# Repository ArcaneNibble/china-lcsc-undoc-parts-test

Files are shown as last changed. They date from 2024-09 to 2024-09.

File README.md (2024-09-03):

# China / LCSC poorly-documented parts tester PCB

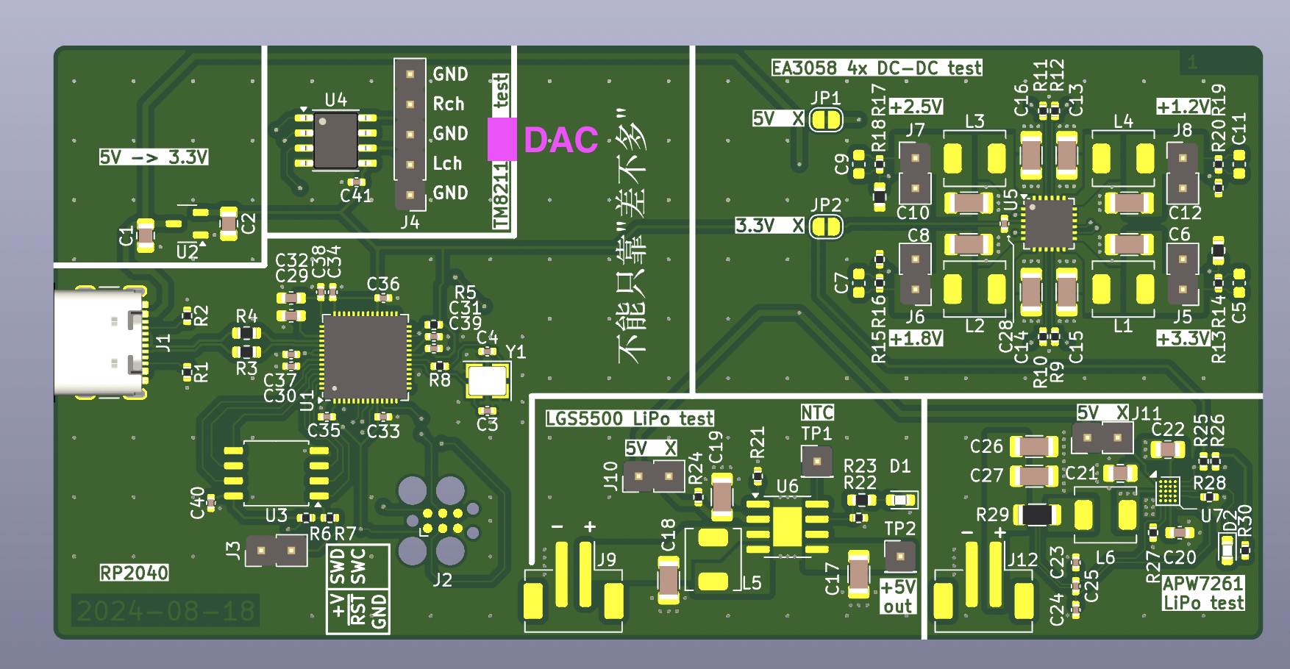
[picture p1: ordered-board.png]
3d render of board


## TM8211

This is a cheap I2S DAC that looks like it is intended for set-top-boxes. Allegedly, there is no minium clock speed. The goal is to determine if this is indeed true, in which case it can be bit-banged instead of doing proper I2S with a continuously-running clock. If it were to be the case, we would want to know the output impedance of the DAC.

### Status

I haven't managed to get this chip to output anything at all so far, even with a continuous clock. Further investigation needed.

## EA3058

This is a 4-channel buck converter. I wanted to characterize its performance in more detail than the few graphs in the datasheet.

### Status

The zero-load performance seems quite poor on the 1.2 V output. Further measurements have not been made yet.

## LGS5500

This is a LiPo charger and boost converter with automagic power path / load sharing. It appears to be perfectly-suited for battery-powered "maker" projects, especially ones that need 5 V and/or want to be able to push batteries to ~3 V rather than ~3.4 V (with an ultra-low-dropout regulator) or even higher voltages (using less and less of the battery capacity). Once again I wanted to characterize the performance in more detail than in the datasheet.

### Status

There is somewhat undesired behavior if there is no battery connected. Automagic power path / load sharing appears to work very well, but more measurements need to be made of whether spikes/dips happen. Needs more testing of the boost converter under load.

## APW7261

This is another LiPo charger and boost converter that is especially cheap. It was a bit unclear how (in)convenient it would be to use. It was also a test of using WLCSPs and pushing JLCPCB minimums.

### Status

This is clearly designed for legacy OTG, and it doesn't have the same type of automagic power path / load sharing as the previous part. It was assembled successfully without any issues.

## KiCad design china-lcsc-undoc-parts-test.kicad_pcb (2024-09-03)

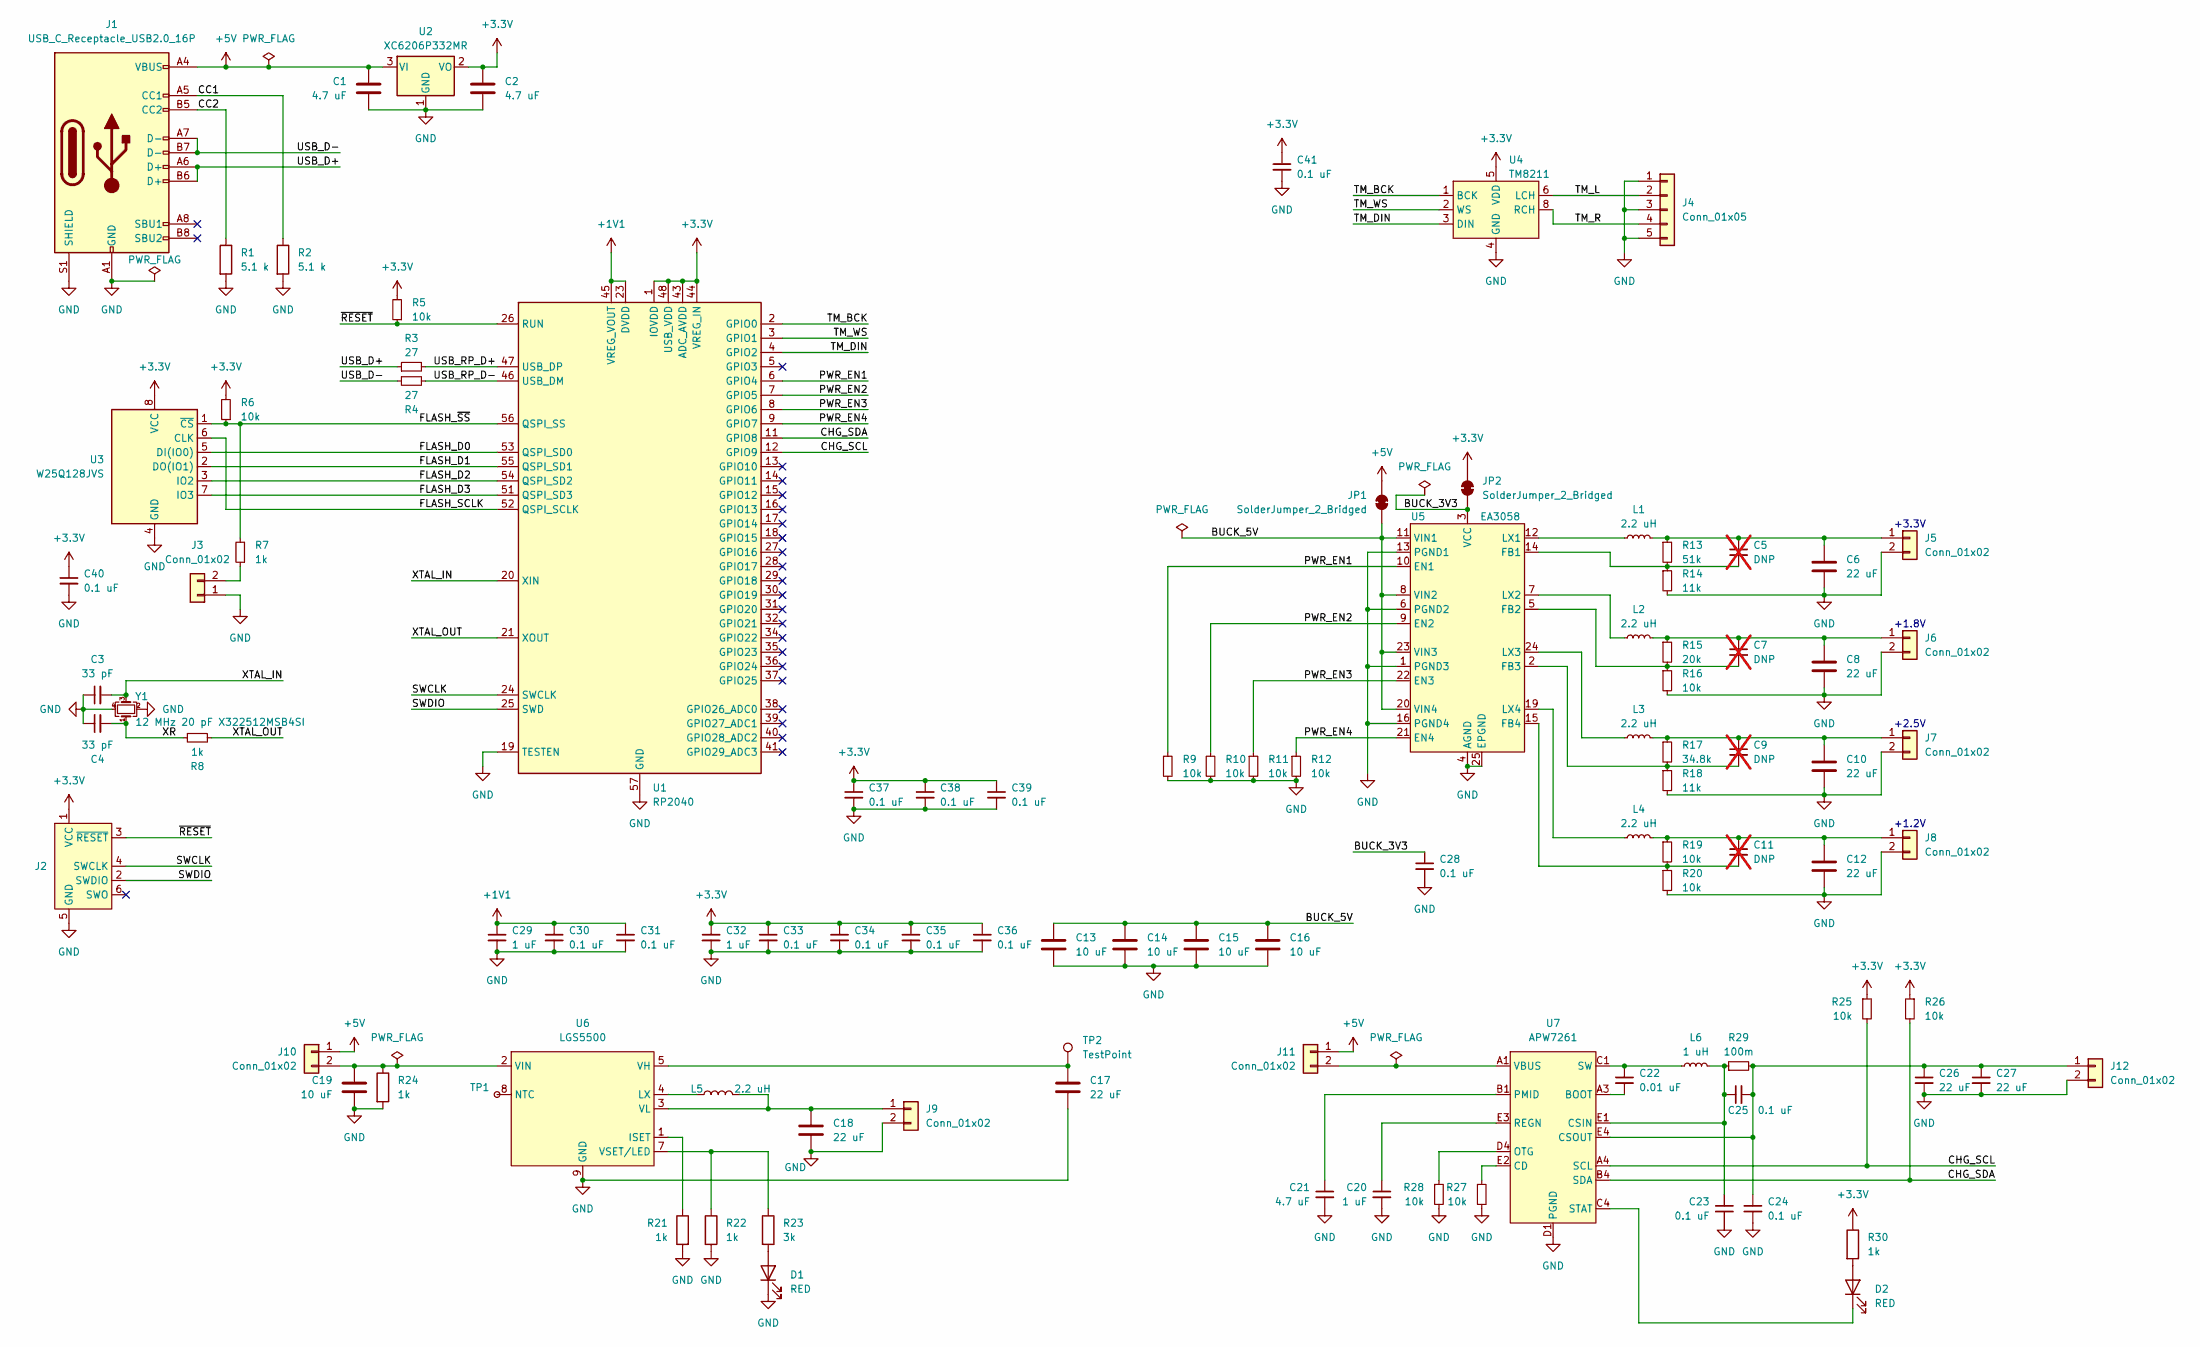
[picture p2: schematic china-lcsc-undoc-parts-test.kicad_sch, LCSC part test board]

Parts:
C1, C2, C21: 4.7 uF; C_0805_2012Metric; LCSC C1779
C3, C4: 33 pF; C_0402_1005Metric; LCSC C1562
C5, C7, C9, C11: DNP; C_0603_1608Metric; not fitted
C6, C8, C10, C12, C17, C18, C26, C27: 22 uF; C_1206_3216Metric; LCSC C12891
C13, C14, C15, C16, C19: 10 uF; C_1206_3216Metric; LCSC C13585
C20, C29, C32: 1 uF; C_0603_1608Metric; LCSC C15849
C22: 0.01 uF; C_0805_2012Metric; LCSC C1710
C23, C24, C25, C28, C30, C31, C33, C34, C35, C36, C37, C38, C39, C40, C41: 0.1 uF; C_0402_1005Metric; LCSC C1525
D1, D2: RED; LED_0603_1608Metric; LCSC C2286
J1: USB_C_Receptacle_USB2.0_16P; USB_C_Receptacle_GCT_USB4105-xx-A_16P_TopMnt_Horizontal; LCSC C2765186
J2: Conn_ARM_SWD_TagConnect_TC2030; Tag-Connect_TC2030-IDC-FP_2x03_P1.27mm_Vertical
J3, J5, J6, J7, J8, J10, J11: Conn_01x02; PinHeader_1x02_P2.54mm_Vertical
J4: Conn_01x05; PinHeader_1x05_P2.54mm_Vertical
J9, J12: Conn_01x02; JST_PH_B2B-PH-SM4-TB_1x02-1MP_P2.00mm_Vertical; LCSC C160352
JP1, JP2: SolderJumper_2_Bridged; SolderJumper-2_P1.3mm_Bridged_RoundedPad1.0x1.5mm
L1, L2, L3, L4, L5: 2.2 uH; L_Changjiang_FXL0420; LCSC C167206
L6: 1 uH; L_Changjiang_FXL0420; LCSC C167203
R1, R2: 5.1 k; R_0402_1005Metric; LCSC C25905
R3, R4: 27; R_0603_1608Metric; LCSC C25190
R5, R6, R9, R10, R11, R12, R16, R19, R20, R25, R26, R27, R28: 10k; R_0402_1005Metric; LCSC C25744
R7, R8, R21, R22, R24, R30: 1k; R_0402_1005Metric; LCSC C11702
R13: 51k; R_0402_1005Metric; LCSC C25794
R14, R18: 11k; R_0603_1608Metric; LCSC C25950
R15: 20k; R_0402_1005Metric; LCSC C25765
R17: 34.8k; R_0402_1005Metric; LCSC C47493
R23: 3k; R_0603_1608Metric; LCSC C4211
R29: 100m; R_1206_3216Metric; LCSC C188071
TP1: TestPoint_Small; PinHeader_1x01_P2.54mm_Vertical
TP2: TestPoint; PinHeader_1x01_P2.54mm_Vertical
U1: RP2040; QFN-56-1EP_7x7mm_P0.4mm_EP3.2x3.2mm; LCSC C2040
U2: XC6206P332MR; SOT-23-3; LCSC C5446
U3: W25Q128JVS; SOIC-8_5.23x5.23mm_P1.27mm; LCSC C97521
U4: TM8211; SOIC-8_3.9x4.9mm_P1.27mm; LCSC C92003
U5: EA3058; QFN-24-1EP_4x4mm_P0.5mm_EP2.6x2.6mm; LCSC C575412
U6: LGS5500; SOIC-8-1EP_3.9x4.9mm_P1.27mm_EP2.41x3.3mm; LCSC C5280699
U7: APW7261; WLCSP-24_1.76x2.03mm_P0.4mm; LCSC C691404
Y1: 12 MHz 20 pF X322512MSB4SI; Crystal_SMD_3225-4Pin_3.2x2.5mm; LCSC C9002

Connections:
+1V1: C29.1, C30.1, C31.1, U1.23 (DVDD), U1.45 (VREG_VOUT), U1.50 (DVDD)
+3.3V: C2.1, C32.1, C33.1, C34.1, C35.1, C36.1, C37.1, C38.1, C39.1, C40.1, C41.1, J2.1 (VCC), JP2.1 (A), R5.2, R6.2, R25.1, R26.1, R30.1, U1.1 (IOVDD), U1.10 (IOVDD), U1.22 (IOVDD), U1.33 (IOVDD), U1.42 (IOVDD), U1.43 (ADC_AVDD), U1.44 (VREG_IN), U1.48 (USB_VDD), U1.49 (IOVDD), U2.2 (VO), U3.8 (VCC), U4.5 (VDD)
+5V: C1.1, J1.A4 (VBUS), J1.A9 (VBUS), J1.B4 (VBUS), J1.B9 (VBUS), J10.1, J11.1, JP1.1 (A), U2.3 (VI)
/BUCK_3V3: C28.1, JP2.2 (B), U5.3 (VCC)
/BUCK_5V: C13.1, C14.1, C15.1, C16.1, JP1.2 (B), U5.8 (VIN2), U5.11 (VIN1), U5.20 (VIN4), U5.23 (VIN3)
/CC1: J1.A5 (CC1), R2.1
/CC2: J1.B5 (CC2), R1.1
/CHG_SCL: R25.2, U1.12 (GPIO9), U7.A4 (SCL)
/CHG_SDA: R26.2, U1.11 (GPIO8), U7.B4 (SDA)
/FLASH_D0: U1.53 (QSPI_SD0), U3.5 (DI(IO0))
/FLASH_D1: U1.55 (QSPI_SD1), U3.2 (DO(IO1))
/FLASH_D2: U1.54 (QSPI_SD2), U3.3 (IO2)
/FLASH_D3: U1.51 (QSPI_SD3), U3.7 (IO3)
/FLASH_SCLK: U1.52 (QSPI_SCLK), U3.6 (CLK)
/FLASH_~SS: R6.1, R7.2, U1.56 (QSPI_SS), U3.1 (~CS)
/PWR_EN1: R9.1, U1.6 (GPIO4), U5.10 (EN1)
/PWR_EN2: R10.1, U1.7 (GPIO5), U5.9 (EN2)
/PWR_EN3: R11.1, U1.8 (GPIO6), U5.22 (EN3)
/PWR_EN4: R12.1, U1.9 (GPIO7), U5.21 (EN4)
/SWCLK: J2.4 (SWCLK), U1.24 (SWCLK)
/SWDIO: J2.2 (SWDIO), U1.25 (SWD)
/TM_BCK: U1.2 (GPIO0), U4.1 (BCK)
/TM_DIN: U1.4 (GPIO2), U4.3 (DIN)
/TM_L: J4.2, U4.6 (LCH)
/TM_R: J4.4, U4.8 (RCH)
/TM_WS: U1.3 (GPIO1), U4.2 (WS)
/USB_D+: J1.A6 (D+), J1.B6 (D+), R3.1
/USB_D-: J1.A7 (D-), J1.B7 (D-), R4.1
/USB_RP_D+: R3.2, U1.47 (USB_DP)
/USB_RP_D-: R4.2, U1.46 (USB_DM)
/XR: C4.2, R8.1, Y1.1
/XTAL_IN: C3.2, U1.20 (XIN), Y1.3
/XTAL_OUT: R8.2, U1.21 (XOUT)
/~RESET: J2.3 (~RESET), R5.1, U1.26 (RUN)
GND: C1.2, C2.2, C3.1, C4.1, C6.2, C8.2, C10.2, C12.2, C13.2, C14.2, C15.2, C16.2, C17.2, C18.2, C19.2, C20.2, C21.2, C23.2, C24.2, C26.2, C27.2, C28.2, C29.2, C30.2, C31.2, C32.2, C33.2, C34.2, C35.2, C36.2, C37.2, C38.2, C39.2, C40.2, C41.2, D1.1 (K), J1.A1 (GND), J1.A12 (GND), J1.B1 (GND), J1.B12 (GND), J1.S1 (SHIELD), J2.5 (GND), J3.1, J4.1, J4.3, J4.5, J5.2, J6.2, J7.2, J8.2, J9.2, J12.2, R1.2, R2.2, R9.2, R10.2, R11.2, R12.2, R14.2, R16.2, R18.2, R20.2, R21.2, R22.2, R24.2, R27.2, R28.2, U1.19 (TESTEN), U1.57 (GND), U2.1 (GND), U3.4 (GND), U4.4 (GND), U5.1 (PGND3), U5.4 (AGND), U5.6 (PGND2), U5.13 (PGND1), U5.16 (PGND4), U5.25 (EPGND), U6.9 (GND), U7.D1 (PGND), U7.D2 (PGND), U7.D3 (PGND), Y1.2, Y1.4
unnamed: C21.1, U7.B1 (PMID), U7.B2 (PMID), U7.B3 (PMID)
unnamed: C22.1, L6.1, U7.C1 (SW), U7.C2 (SW), U7.C3 (SW)
unnamed: D1.2 (A), R23.2
unnamed: D2.2 (A), R30.2
unnamed: D2.1 (K), U7.C4 (STAT)
unnamed: J3.2, R7.1
unnamed: C5.1, C6.1, J5.1, L1.2, R13.1
unnamed: C7.1, C8.1, J6.1, L2.2, R15.1
unnamed: C9.1, C10.1, J7.1, L3.2, R17.1
unnamed: C11.1, C12.1, J8.1, L4.2, R19.1
unnamed: C18.1, J9.1, L5.2, U6.3 (VL)
unnamed: C19.1, J10.2, R24.1, U6.2 (VIN)
unnamed: J11.2, U7.A1 (VBUS), U7.A2 (VBUS)
unnamed: C24.1, C25.2, C26.1, C27.1, J12.1, R29.2, U7.E4 (CSOUT)
unnamed: C5.2, R13.2, R14.1, U5.14 (FB1)
unnamed: C7.2, R15.2, R16.1, U5.5 (FB2)
unnamed: C9.2, R17.2, R18.1, U5.2 (FB3)
unnamed: C11.2, R19.2, R20.1, U5.15 (FB4)
unnamed: L1.1, U5.12 (LX1)
unnamed: L2.1, U5.7 (LX2)
unnamed: L3.1, U5.24 (LX3)
unnamed: L4.1, U5.19 (LX4)
unnamed: R21.1, U6.1 (ISET)
unnamed: L5.1, U6.4 (LX)
unnamed: TP1.1, U6.8 (NTC)
unnamed: C17.1, TP2.1, U6.5 (VH)
unnamed: R22.1, R23.1, U6.7 (VSET/LED)
unnamed: C22.2, U7.A3 (BOOT)
unnamed: R27.1, U7.E2 (CD)
unnamed: C23.1, C25.1, L6.2, R29.1, U7.E1 (CSIN)
unnamed: R28.1, U7.D4 (OTG)
unnamed: C20.1, U7.E3 (REGN)

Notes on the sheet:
+1.2V
+2.5V
+1.8V
+3.3V

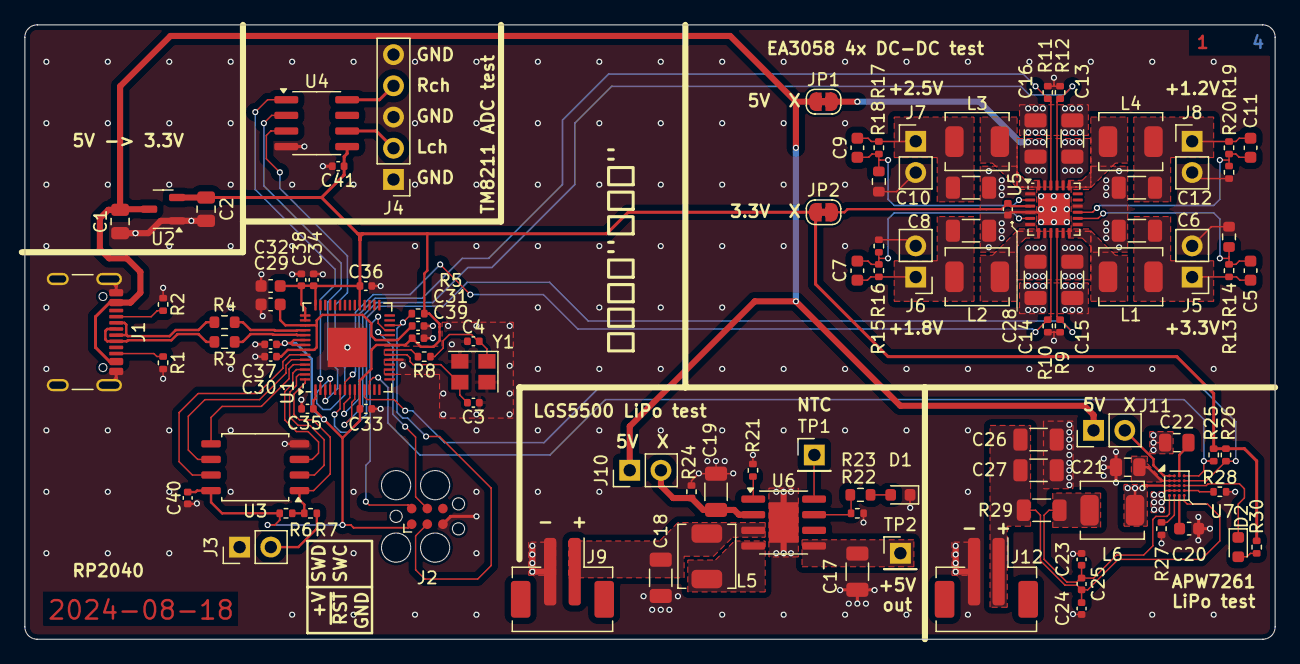
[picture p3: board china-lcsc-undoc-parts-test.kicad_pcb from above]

Board: 4 copper layers, 101.8 x 50.0 mm, 103 parts (0 on the bottom side), 67 nets.

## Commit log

2024-09-03 Initial reimport commit
    [china-lcsc-undoc-parts-test.kicad_pcb, china-lcsc-undoc-parts-test.kicad_sch]
2024-09-03 reword note about lipos
